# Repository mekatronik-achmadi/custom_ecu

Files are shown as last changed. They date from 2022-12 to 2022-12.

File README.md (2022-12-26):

# Custom Engine Control

This project try to build a custom engine control as flexible as possible, based on STM32 chip series run on RTOS like ChibiOS/RT or FreeRTOS.

## Overview
- Based on STM32F0/F1 series and H11L1 Schmitt Trigger to monitor engine process in real-time and controlling using IRF5xx FET series.
- Provide Serial TTL to USB port for easy realtime monitoring and more custom settings.
- Reading both TPS and Crank tooth for controlling a pair Injectors and a pair Ignition Coils.
- The design currently in very early stage and not for end user usage.

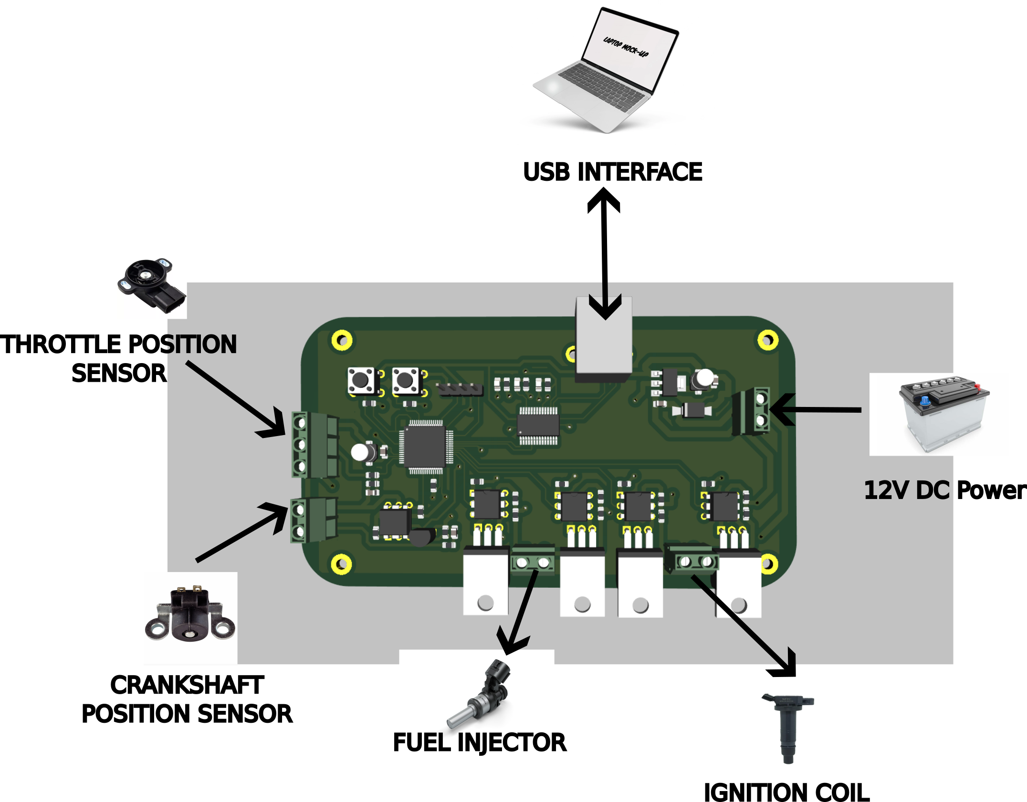
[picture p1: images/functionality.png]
images


## Crankshaft Position Sensor Alternative

Using Photo Interrupter Sensor and Encoder Wheel with one tooth missing as counter reset.

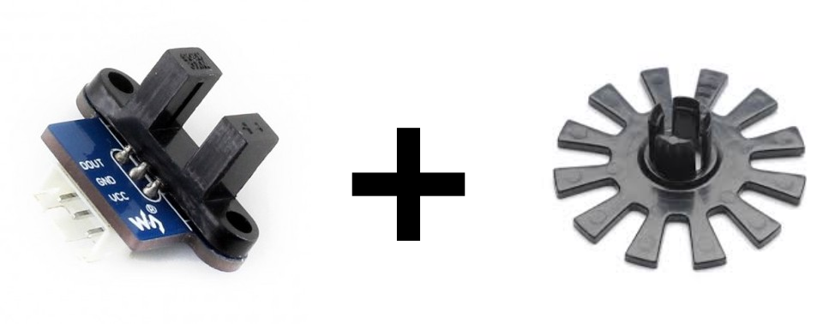
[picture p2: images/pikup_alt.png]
images


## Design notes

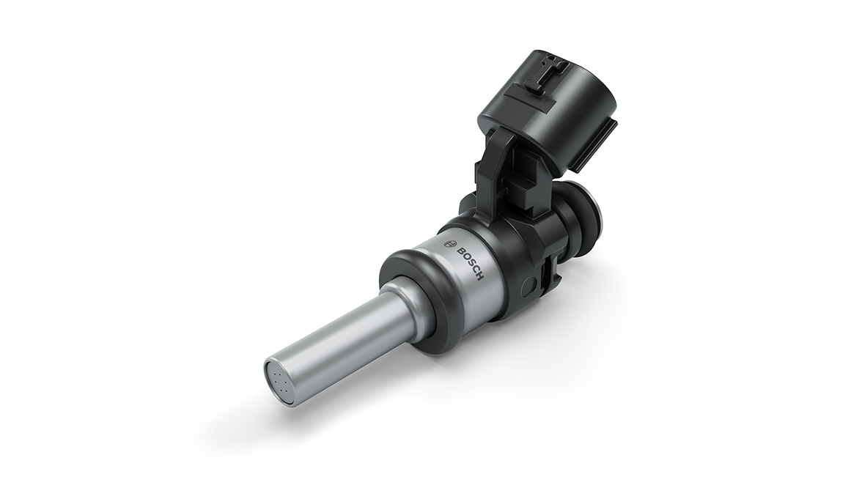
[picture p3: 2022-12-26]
images/injector.jpg

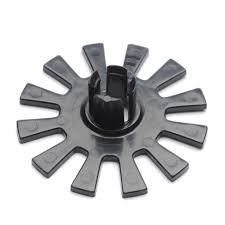
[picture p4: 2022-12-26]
images/interupter.jpg

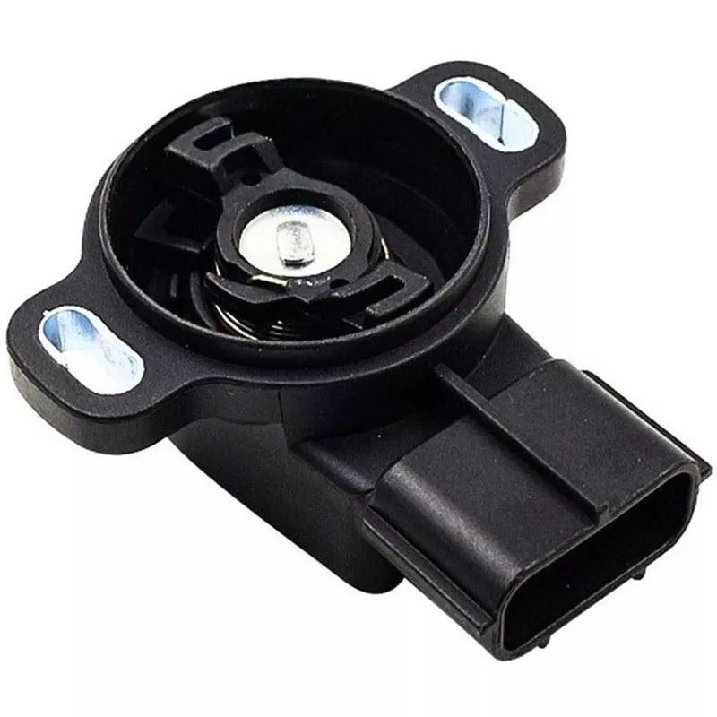
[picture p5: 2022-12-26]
images/tps.png

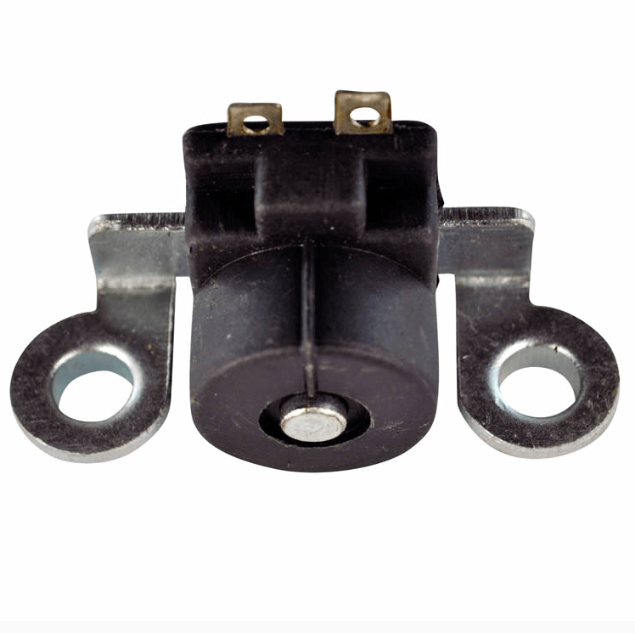
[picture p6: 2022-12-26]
images/pickup.png

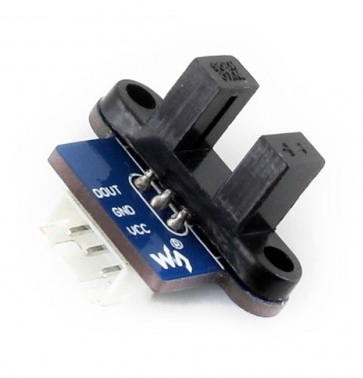
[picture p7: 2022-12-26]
images/photointerrupter.jpg

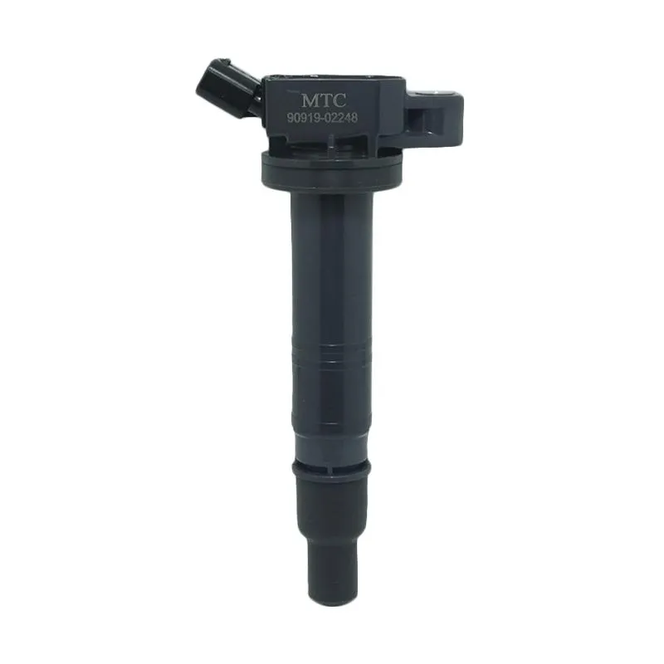
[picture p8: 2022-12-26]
images/coil.png

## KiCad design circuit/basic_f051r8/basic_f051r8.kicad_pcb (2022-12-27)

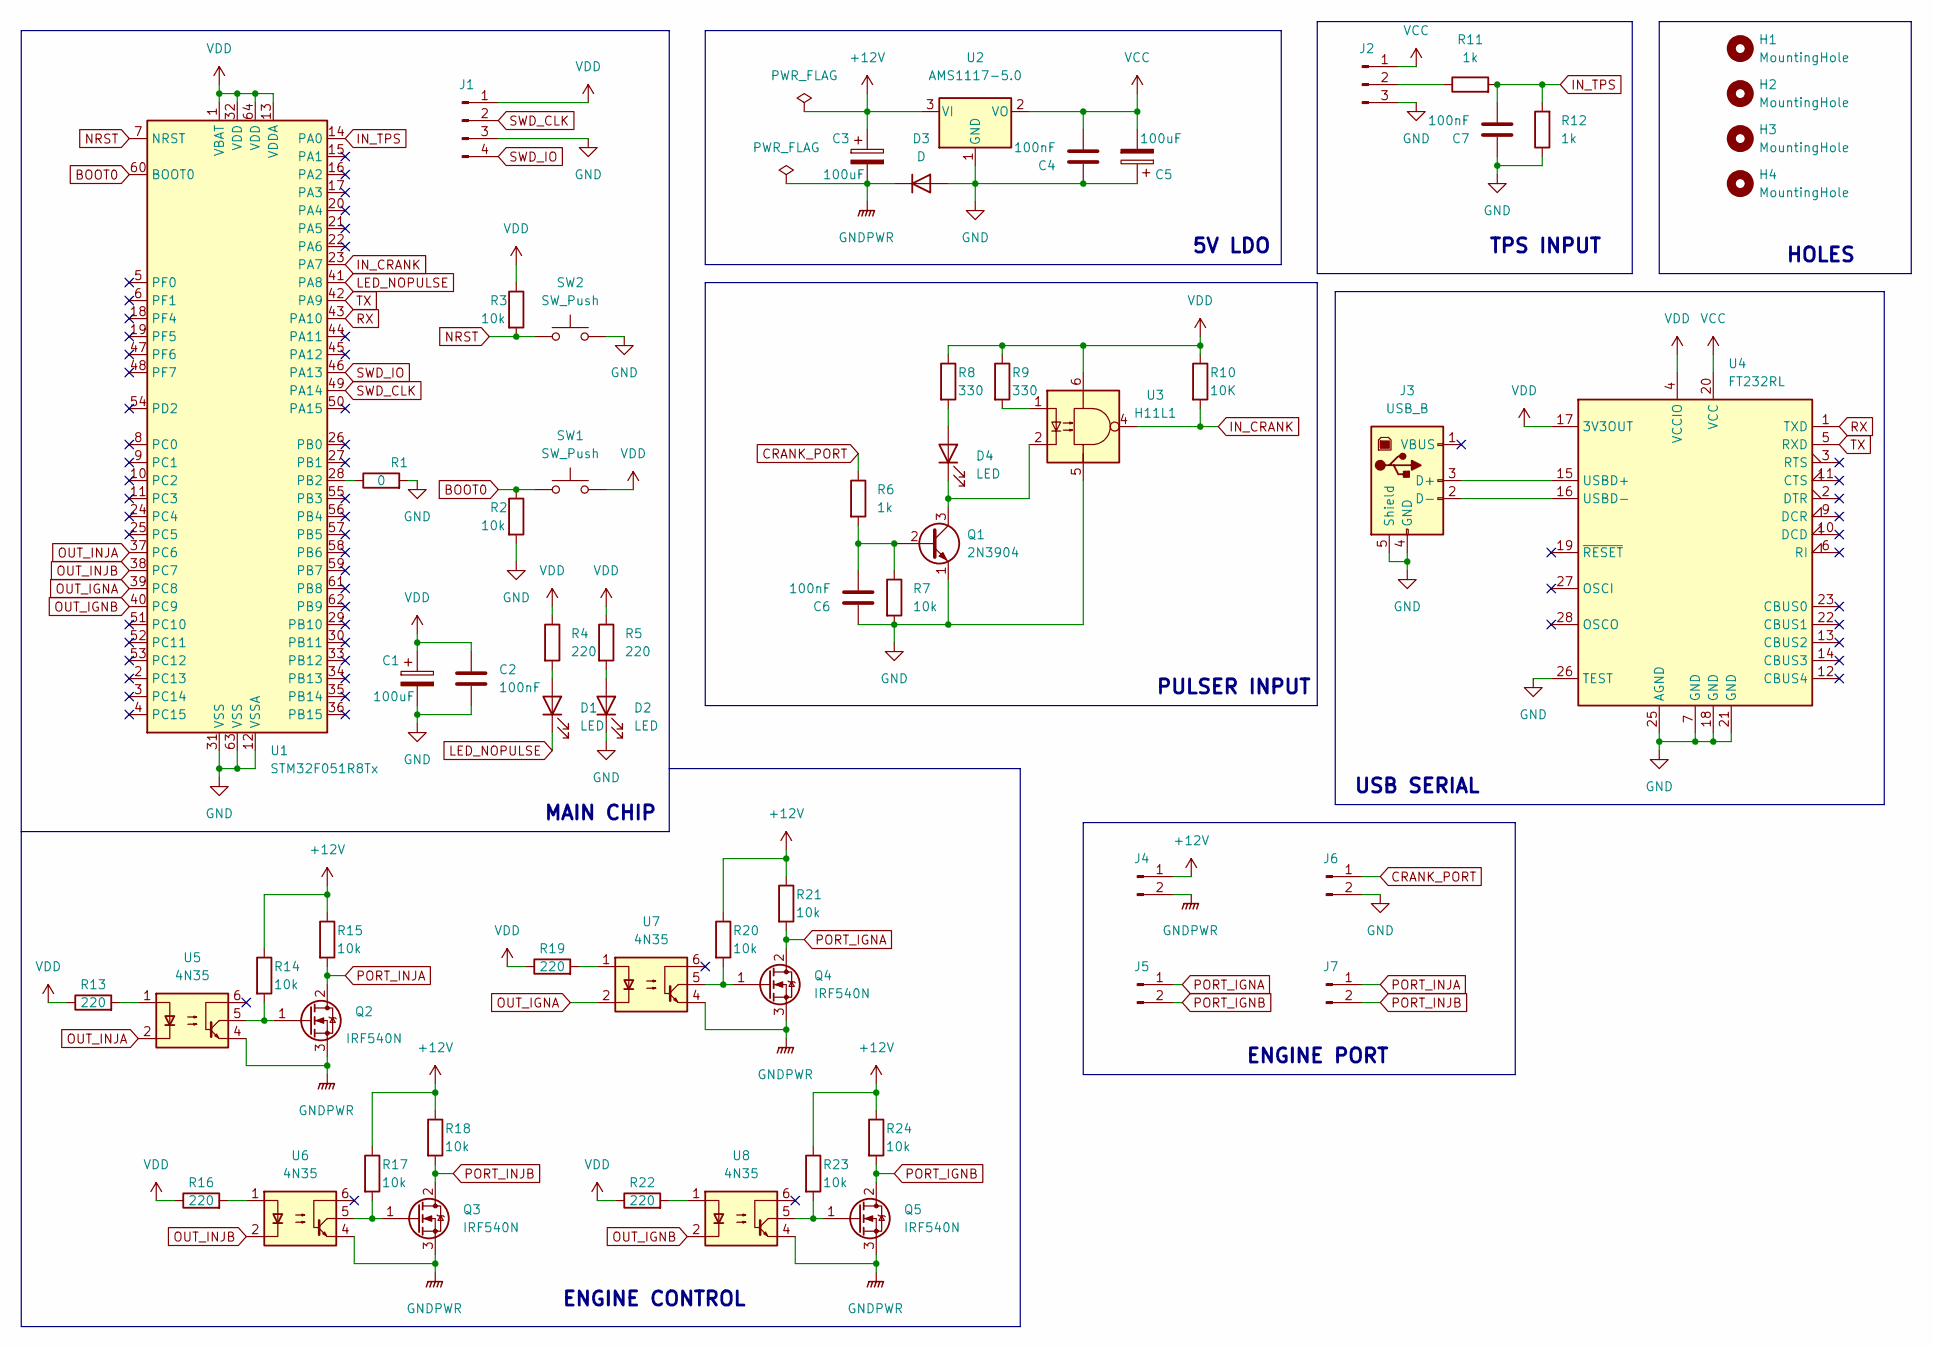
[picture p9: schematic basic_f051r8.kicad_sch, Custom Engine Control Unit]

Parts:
C1, C5: 100uF; C_Elec_4x5.4
C2, C4, C6, C7: 100nF; C_0805_2012Metric_Pad1.18x1.45mm_HandSolder
C3: 100uF; C_0805_2012Metric_Pad1.18x1.45mm_HandSolder
D1, D2, D4: LED; LED_0805_2012Metric_Pad1.15x1.40mm_HandSolder
D3: D; D_SMA-SMB_Universal_Handsoldering
H1, H2, H3, H4: MountingHole; MountingHole_2.5mm_Pad
J1: Conn_01x04_Male; PinHeader_1x04_P2.54mm_Vertical
J2: Conn_01x03_Male; TerminalBlock_Altech_AK300-3_P5.00mm
J3: USB_B; USB_B_Lumberg_2411_02_Horizontal
J4, J5, J6, J7: Conn_01x02_Male; TerminalBlock_Altech_AK300-2_P5.00mm
Q1: 2N3904; TO-92_Inline
Q2, Q3, Q4, Q5: IRF540N; TO-220-3_Horizontal_TabUp
R1: 0; R_0805_2012Metric_Pad1.20x1.40mm_HandSolder
R2, R3, R7, R14, R15, R17, R18, R20, R21, R23, R24: 10k; R_0805_2012Metric_Pad1.20x1.40mm_HandSolder
R4, R5, R13, R16, R19, R22: 220; R_0805_2012Metric_Pad1.20x1.40mm_HandSolder
R6, R11, R12: 1k; R_0805_2012Metric_Pad1.20x1.40mm_HandSolder
R8, R9: 330; R_0805_2012Metric_Pad1.20x1.40mm_HandSolder
R10: 10K; R_0805_2012Metric_Pad1.20x1.40mm_HandSolder
SW1, SW2: SW_Push; SW_PUSH_6mm
U1: STM32F051R8Tx; LQFP-64_10x10mm_P0.5mm
U2: AMS1117-5.0; SOT-223-3_TabPin2
U3: H11L1; DIP-6_W7.62mm
U4: FT232RL; SSOP-28_5.3x10.2mm_P0.65mm
U5, U6, U7, U8: 4N35; DIP-6_W7.62mm

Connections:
+12V: C3.1, J4.1, R14.1, R15.1, R17.1, R18.1, R20.1, R21.1, R23.1, R24.1, U2.3 (VI)
BOOT0: R2.1, SW1.1, U1.60 (BOOT0)
CRANK_PORT: J6.1, R6.1
GND: C1.2, C2.2, C4.1, C5.1, C6.1, C7.1, D2.1 (K), D3.2 (A), J1.3, J2.3, J3.4 (GND), J3.5 (Shield), J6.2, Q1.1 (E), R1.2, R2.2, R7.2, R12.1, SW2.2, U1.12 (VSSA), U1.31 (VSS), U1.63 (VSS), U2.1 (GND), U3.5, U4.7 (GND), U4.18 (GND), U4.21 (GND), U4.25 (AGND), U4.26 (TEST)
GNDPWR: C3.2, D3.1 (K), J4.2, Q2.3 (S), Q3.3 (S), Q4.3 (S), Q5.3 (S), U5.4, U6.4, U7.4, U8.4
IN_CRANK: R10.2, U1.23 (PA7), U3.4
IN_TPS: C7.2, R11.2, R12.2, U1.14 (PA0)
LED_NOPULSE: D1.1 (K), U1.41 (PA8)
NRST: R3.2, SW2.1, U1.7 (NRST)
unnamed: C6.2, Q1.2 (B), R6.2, R7.1
unnamed: D1.2 (A), R4.2
unnamed: D2.2 (A), R5.2
unnamed: D4.1 (K), Q1.3 (C), U3.2
unnamed: D4.2 (A), R8.2
unnamed: J2.2, R11.1
unnamed: Q2.1 (G), R14.2, U5.5
unnamed: Q3.1 (G), R17.2, U6.5
unnamed: Q4.1 (G), R20.2, U7.5
unnamed: Q5.1 (G), R23.2, U8.5
unnamed: R1.1, U1.28 (PB2)
unnamed: R9.2, U3.1
unnamed: R13.2, U5.1
unnamed: R16.2, U6.1
unnamed: R19.2, U7.1
unnamed: R22.2, U8.1
unnamed: J3.3 (D+), U4.15 (USBD+)
unnamed: J3.2 (D-), U4.16 (USBD-)
OUT_IGNA: U1.39 (PC8), U7.2
OUT_IGNB: U1.40 (PC9), U8.2
OUT_INJA: U1.37 (PC6), U5.2
OUT_INJB: U1.38 (PC7), U6.2
PORT_IGNA: J5.1, Q4.2 (D), R21.2
PORT_IGNB: J5.2, Q5.2 (D), R24.2
PORT_INJA: J7.1, Q2.2 (D), R15.2
PORT_INJB: J7.2, Q3.2 (D), R18.2
RX: U1.43 (PA10), U4.1 (TXD)
SWD_CLK: J1.2, U1.49 (PA14)
SWD_IO: J1.4, U1.46 (PA13)
TX: U1.42 (PA9), U4.5 (RXD)
VCC: C4.2, C5.2, J2.1, U2.2 (VO), U4.20 (VCC)
VDD: C1.1, C2.1, J1.1, R3.1, R4.1, R5.1, R8.1, R9.1, R10.1, R13.1, R16.1, R19.1, R22.1, SW1.2, U1.1 (VBAT), U1.13 (VDDA), U1.32 (VDD), U1.64 (VDD), U3.6, U4.4 (VCCIO), U4.17 (3V3OUT)

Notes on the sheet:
PULSER INPUT
MAIN CHIP
5V LDO
USB SERIAL
ENGINE PORT
HOLES
TPS INPUT
ENGINE CONTROL

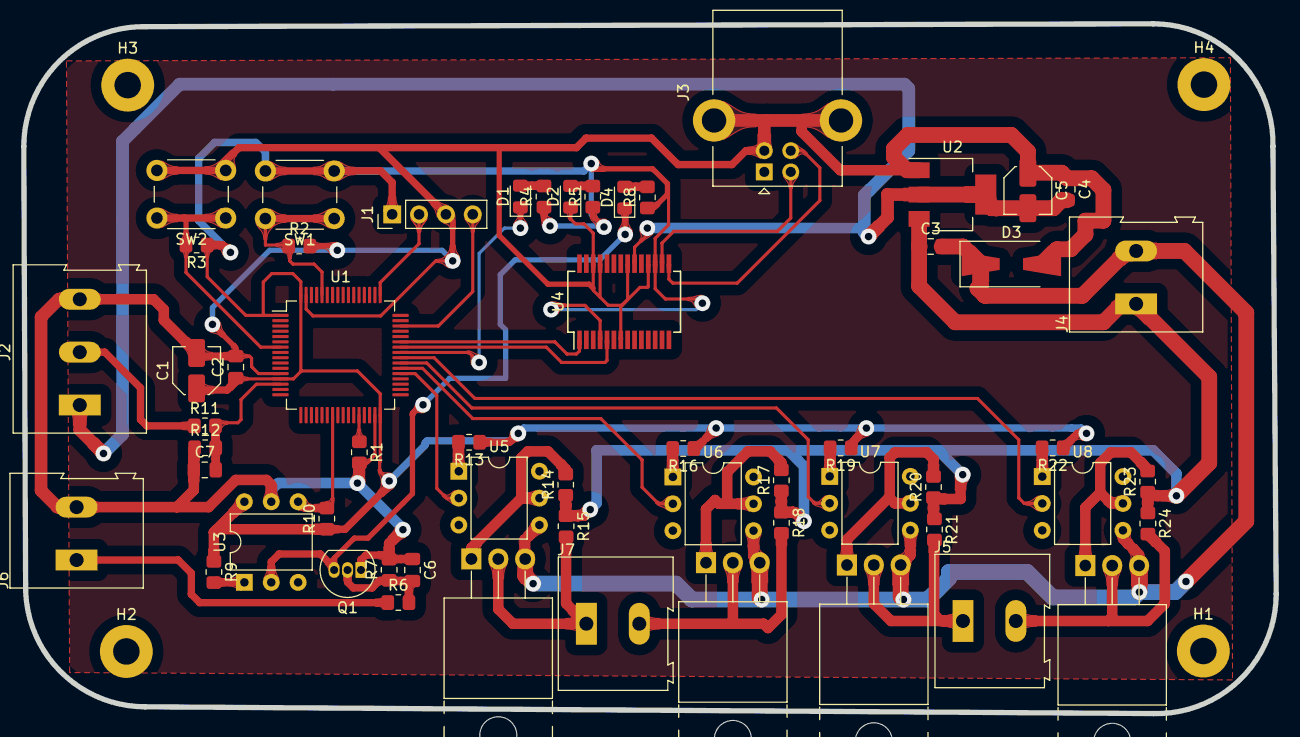
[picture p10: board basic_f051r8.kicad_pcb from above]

Board: 2 copper layers, 118.4 x 65.2 mm, 61 parts (0 on the bottom side), 41 nets.

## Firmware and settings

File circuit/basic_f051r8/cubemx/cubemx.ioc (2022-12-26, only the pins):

Mcu.UserName=STM32F051R8Tx
PA0.Signal=ADC_IN0
PA10.Signal=USART1_RX
PA13.Signal=SYS_SWDIO
PA14.Signal=SYS_SWCLK
PA7.Signal=S_TIM3_CH2
PA8.Signal=GPIO_Output
PA9.Signal=USART1_TX
PC6.Signal=GPIO_Output
PC7.Signal=GPIO_Output
PC8.Signal=GPIO_Output
PC9.Signal=GPIO_Output

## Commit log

2022-12-26 Start Circuit
    [basic_f051r8.kicad_pcb, basic_f051r8.kicad_sch]
2022-12-26 Schematic Done
    [basic_f051r8.kicad_sch]
2022-12-26 Footprint Assigment
    [basic_f051r8.kicad_sch]
2022-12-26 PCB Layout (No Route)
    [basic_f051r8.kicad_pcb, basic_f051r8.kicad_sch]
2022-12-26 PCB 3D components
    [basic_f051r8.kicad_pcb]
2022-12-26 PCB Draft Done
    [basic_f051r8.kicad_pcb]
2022-12-27 Bill of Material
    [basic_f051r8.kicad_pcb]
2022-12-27 Biaya PCB
